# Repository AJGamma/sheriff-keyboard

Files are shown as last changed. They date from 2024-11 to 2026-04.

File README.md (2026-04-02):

# :gun:Sheriff: A :fire:BLAZINGLY FAST:fire:, Feature-rich Ergonomic Split Keyboard with Thumb Scroll Wheels

- Double rotary encoder on the thumb cluster mapped to arrow keys by default, :fire:BLAZINGLY FAST:fire: for text editing
- Higher keys on the num row, easier to reach
- Similar layout to the more traditional keyboard on notebooks, less mental overload for switching between devices
- Reversible PCB
- Fully generated, including the case, allowing easy modifications
- Configurable case generation
- Both wired and wireless support
- Generated with [Ergogen](https://github.com/ergogen/ergogen)

## :art: Gallery

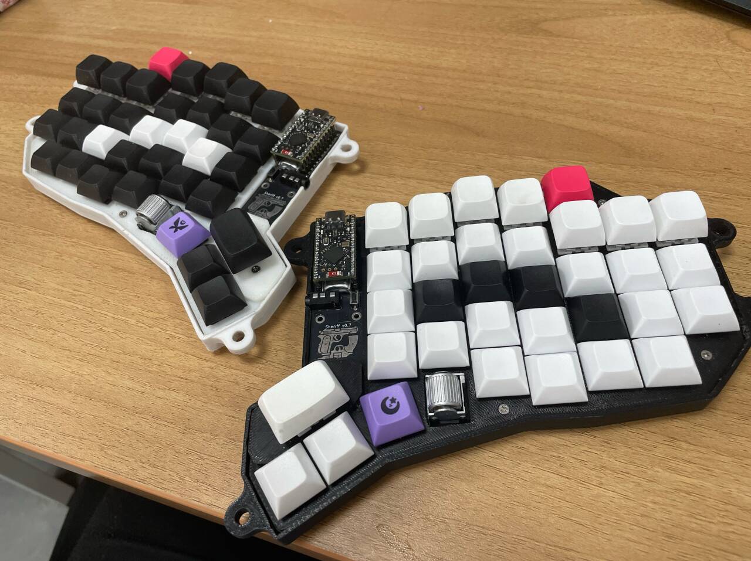
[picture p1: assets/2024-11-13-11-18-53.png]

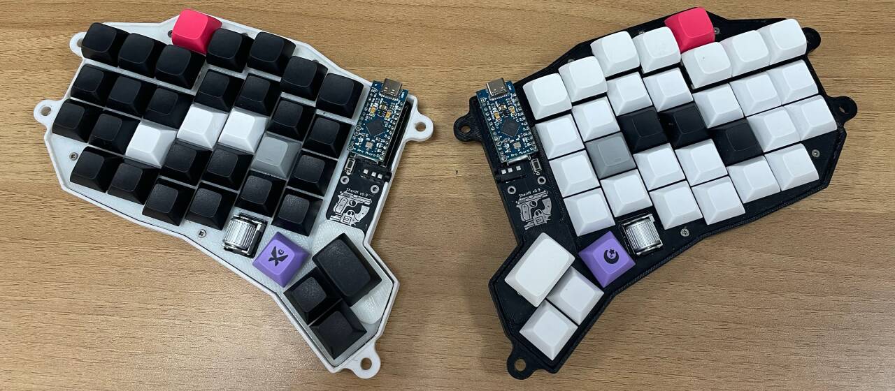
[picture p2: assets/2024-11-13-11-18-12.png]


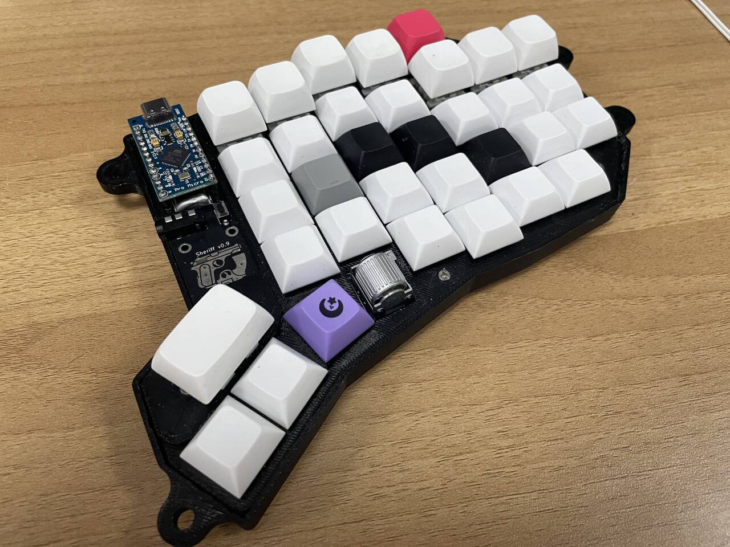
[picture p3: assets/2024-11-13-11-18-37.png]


## :sparkles: Features

### Rotary Encoders
https://github.com/user-attachments/assets/6208423b-0291-43b4-bef7-f6bb31aa5ce3

The core feature of the Sheriff is the easily accessible rotary encoders positioned on the thumb clusters.

#### Encoder behaviors

##### QMK version (`custom_scroll_layers` version)

| Behavior | Key Held  | Left Counter-clockwise | Left Clockwise | Right Counter-clockwise | Right Clockwise |
|---|---|---|---|---|---|
| Arrow key | None | Left | Right | Down | Up |
| Deletion | Backspace | Backspace | Delete | Backspace | Delete |
| Mouse wheel | Esc | Volume-down | Volume-up | Mouse wheel down | Mouse wheel up |
| Repeating | Space | Left | Right | Repeat last key | Repeat last key's alternative |
| Mouse emulation | V | Mouse left | Mouse right | Mouse down | Mouse up |
| Vim motion | W | b | w | } | { |
| Vim motion | E | ge | e | Down | Up |
| Vim undo/redo | U | u | C-r | C-r | u |
| Undo/redo | Y | C-z | C-y | C-y | C-z |
| Undo/redo | Z | C-z | S-C-z | S-C-z | C-z |
| Speed up | 8 | Next activated behavior 8 times | Next activated behavior 8 times | Next activated behavior 8 times | Next activated behavior 8 times |

##### ZMK version

| Behavior | Key Held  | Left Counter-clockwise | Left Clockwise | Right Counter-clockwise | Right Clockwise | Description |
|---|---|---|---|---|---|---|
| Arrow key | None | Left | Right | Down | Up | |
| Deletion | Backspace | Backspace | Delete | Backspace | Delete | |
| Mouse wheel | Esc | Volume-down | Volume-up | Mouse wheel down | Mouse wheel up | Sym layer |
| Repeating | Space | Left | Right | Repeat last key | Repeat last key's alternative | Nav layer |
| Mouse emulation | V | Mouse left | Mouse right | Mouse down | Mouse up | Mouse layer |
| Vim motion | W | b | w | } | { | |
| Vim motion | E | ge | e | Down | Up | |
| Speed up | 8 | Left * 8 | Right * 8 | Down * 8 | Up * 8 | |

### Configurable case generation
The case is generated with [ergogen](https://github.com/ergogen/ergogen), and the config file was written with configurability in mind. There are multiple versions of the case, including `flat`, `tented`, `sinfle-sided tented` and `lifted tented`. The parameters are highly adjustable, and customization can easily be done. See the [doc](/docs/case_customization.md) for more information.

### Easier transitions

One of the motivations for this keyboard is to make the transition from a traditional keyboard to an ergonomic one easier. That's why the default layout is mostly the same as a traditional keyboard, with the only difference being the extra keys in thumb clusters. This way, when you switch back to a traditional keyboard and you reach for the thumb cluster mods, they are simply not there, eliminating any chance of pressing the wrong key.

### Higher up num row

The key caps on the num row are higher up, making them easier to reach.

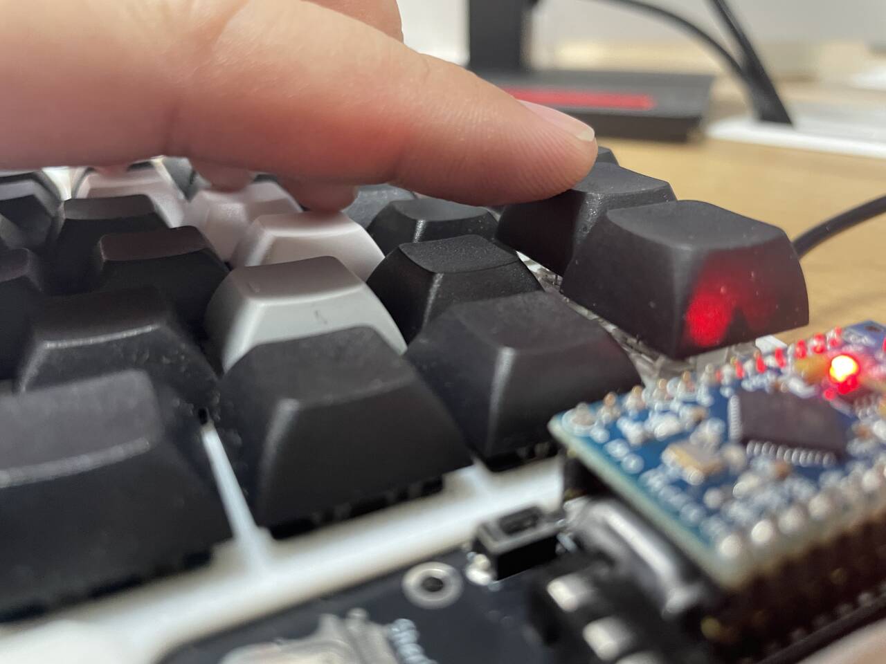
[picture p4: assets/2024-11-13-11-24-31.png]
num_row


### Both wired and wireless support
The PCB has both trrs jacks and battery pins, allowing for both wired and wireless connections.

Both ZMK(wireless) and QMK(wired) firmware are implemented; however, I've encountered several issues with the ZMK firmware, including:
- Two halves unable to pair(swapping boards did not help, neither did flashing reset firmware, and I'm 90% sure nothing's wrong with the firmware)
- Rotary encoder motions sometimes skipped

It's worth noting that I'm not using the official nice!nano boards, but rather the Pro Micro NRF52840 nice!nano v2 compatible boards, which might be the cause of the issues.

## Firmware
Supports wired usage with [QMK](https://qmk.fm/) firmware. Repository [here](https://github.com/AJGamma/sheriff-qmk-config)

Wireless usage is supported with [ZMK](https://zmk.dev/). Repository [here](https://github.com/AJGamma/sheriff-zmk-config). I couldn't get it to work properly though, detail [here](#both-wired-and-wireless-support).

## Layout

Default layer:

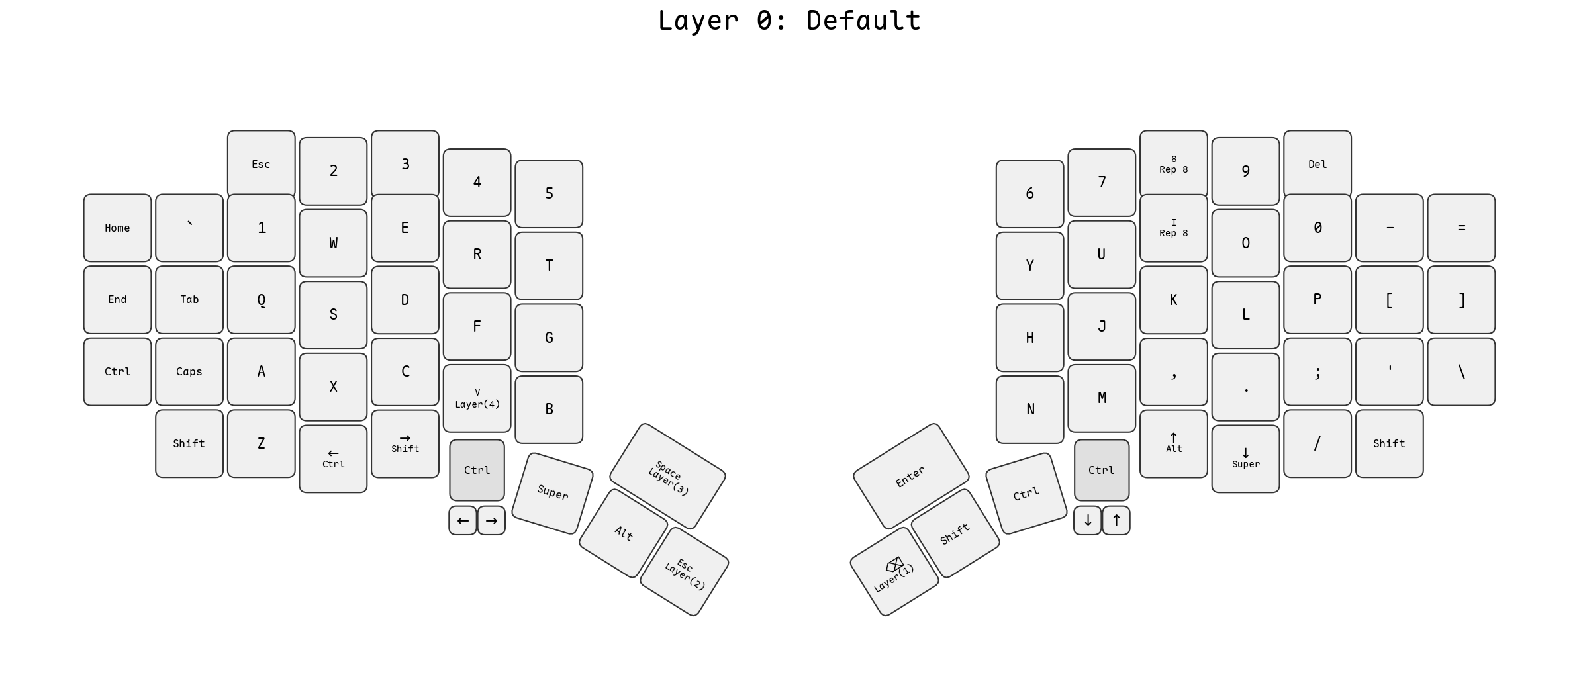
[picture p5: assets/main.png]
default layer


Layer 1:

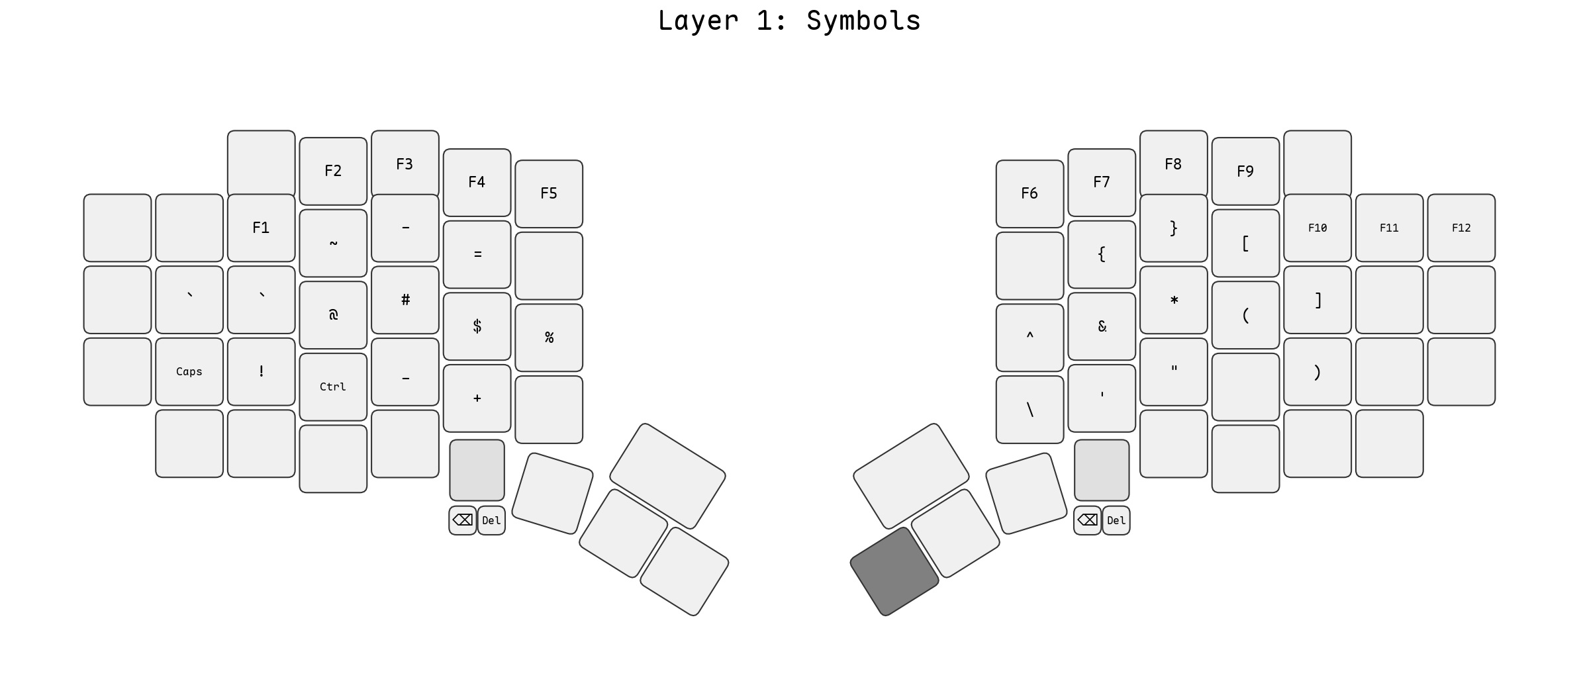
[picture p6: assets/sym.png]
Layer 1


Layer 2:

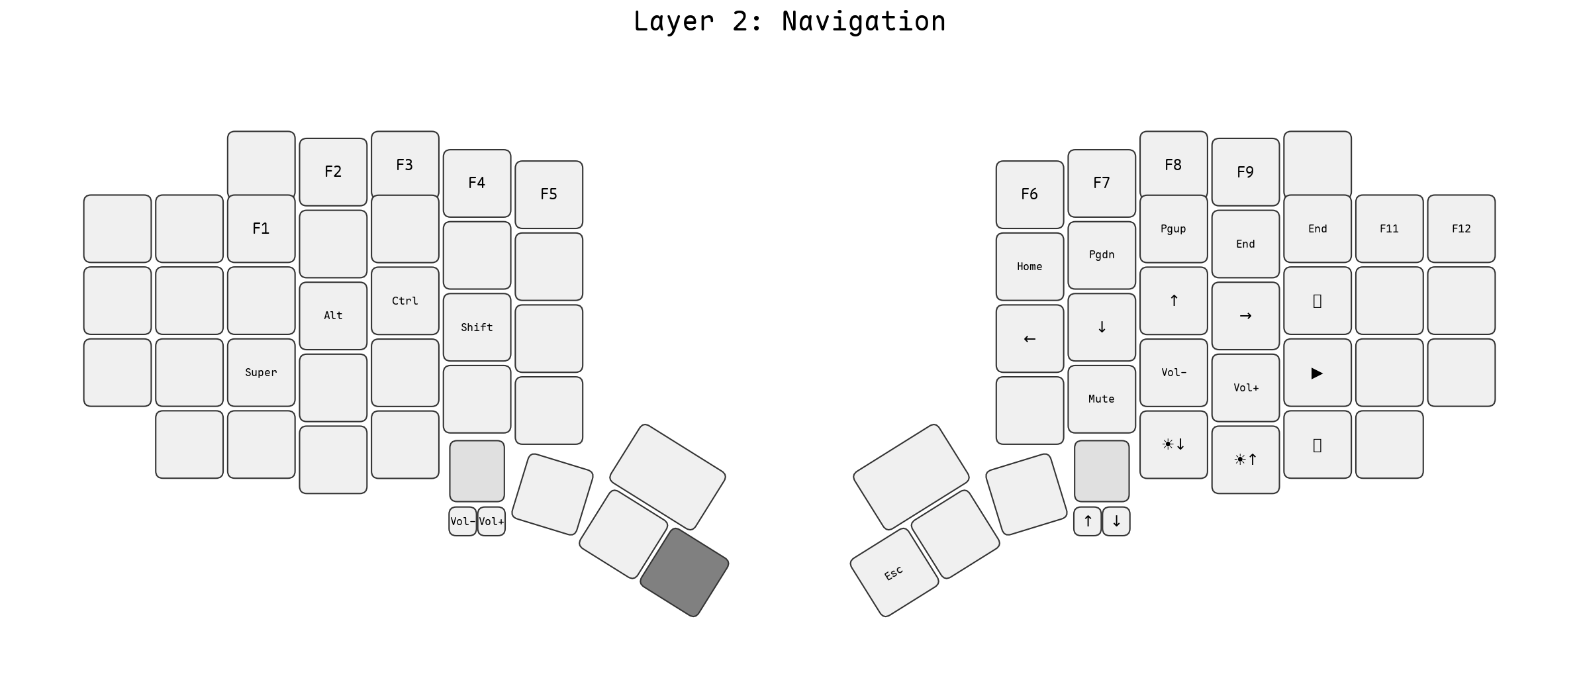
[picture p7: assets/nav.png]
Layer 2


Layer 3:

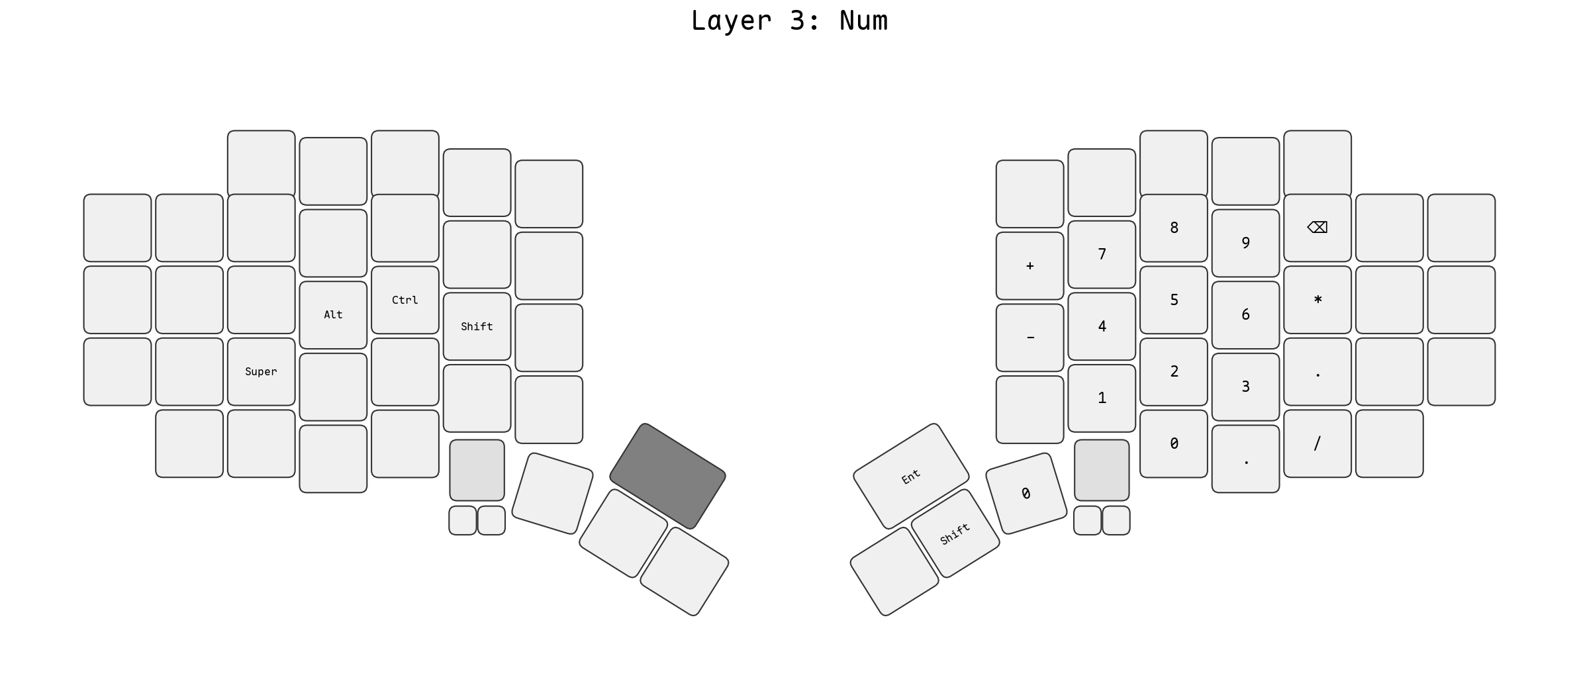
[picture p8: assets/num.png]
Layer 3


## :bulb: Inspirations

- [This amazing video by Christian Selig](https://www.youtube.com/watch?v=7UXsD7nSfDY) inspired me to build my own keyboard.
- I learned a lot from the [Corax](https://github.com/dnlbauer/corax-keyboard) keyboard, and borrowed some code as well.
- The [Arkenswoop](https://github.com/SuperFola/arkenswoop) keyboard has a similar scroll wheel feature, and I fixed my rotary encoder pin definition after checking its kicad file and the information from [this github repo](https://github.com/rroels/EVQWGD001-Pinout).

## Future work
- [ ] Build guide
- [ ] Screen
- [ ] LEDs
- [ ] More intuitive scroll wheel position and orientation
- [ ] New logo
- [ ] 3D-printed key caps
- [ ] More acquirable scroll wheel

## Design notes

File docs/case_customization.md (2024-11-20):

# Case Customization
I have written the [config](../ergogen/config.yaml) file with configurability in mind, and case customization can be easily done by following the instructions below.

## Step by Step

### 1. Modify the [config file](../ergogen/config.yaml)

Simple parameter modification can be done by changing the values in the `units` part of the config file. I have extracted most adjustable and customizable parameters to the `units` part of the config file, including wall thickness, screw diameter, tenting mount thickness, footpad diameter, etc. The variable names are pretty much self-explanatory. Modify the values to your liking.

More complex modifications can be done by modifying the `case` part of the config file. The names are pretty much self-explanatory as well.

### 2. Generate the jscad files
This can be done in two ways:

#### 2.1. Use the web-based deployments of ergogen

There are two online deployments of ergogen: the [official one](https://ergogen.xyz/) and the [unofficial one](https://ergogen.ceoloide.com/)

The online deployments of ergogen do not support uploading js footprint files, so you will receive a couple of error messages if you directly paste the config file into the input box. To avoid this, simply delete or comment out the `pcbs` part of the config file before copying. You can fold the yaml file to make it easier to read and alter.

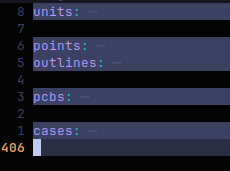
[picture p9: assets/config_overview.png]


The official one directly outputs stl files.

#### 2.2. Run ergogen locally
Install ergogen on your machine by following the instructions on the [ergogen docs](https://docs.ergogen.xyz/usage), then go to the ergogen directory and run the `ergogen` command:
```bash
git clone https://github.com/AJGamma/sheriff-keyboard
cd sheriff-keyboard/ergogen
ergogen .
```
The jscad files should be generated in the `ergogen/output/cases` directory.
<br>
<br>

You should get multiple files, among which you need two: the case file and switchplate file. There are multiple versions of the case, choose one that fits your needs.
### 3. Generate stl files
Use the [OpenJSCAD site](https://neorama.de/) to generate STL files.

### 4. Mirror the models
The generation only take care of the left side, and the right side is just a plain mirror of the left side. Nowadays most 3D-printer slicer software can easily mirror the models, so using a 3D modeling software to mirror the models isn't quite necessary. If you do need to do this, use blender, rhino or whatever. Some online tools may also work.

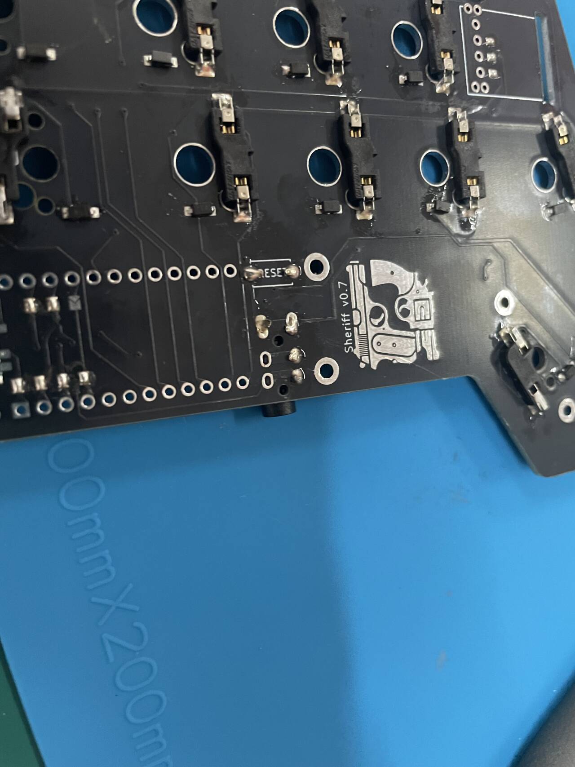
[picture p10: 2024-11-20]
assets/hot_swap.png

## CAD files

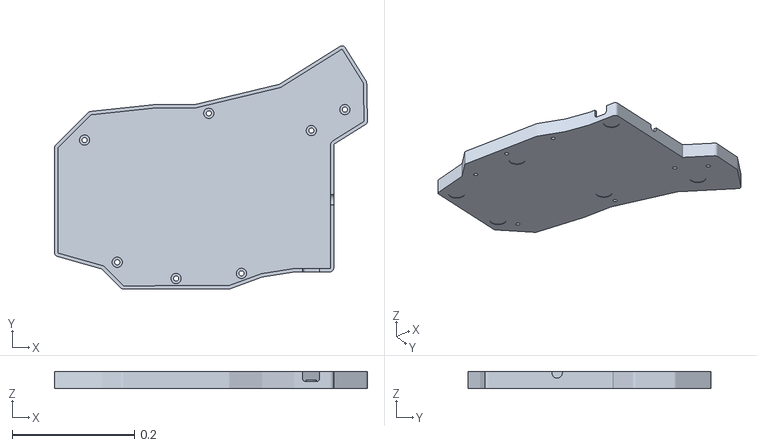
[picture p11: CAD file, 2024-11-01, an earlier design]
v1/3D_prints/cases/flat_case/right.stl
0.512 x 0.398 x 0.0281

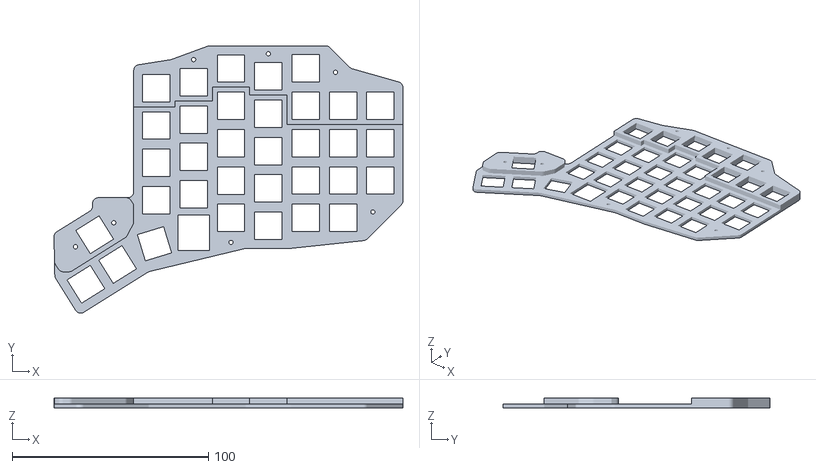
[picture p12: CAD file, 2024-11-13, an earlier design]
v1/3D_prints/cases/switchplates/right.stl
178.0 x 136.4 x 5.00

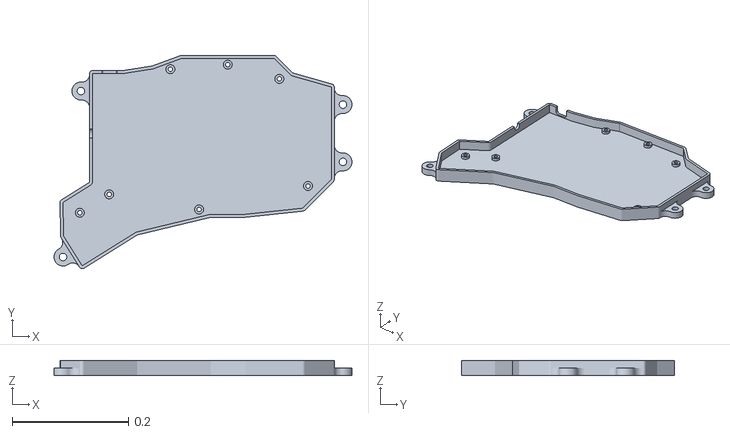
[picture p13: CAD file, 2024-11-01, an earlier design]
v1/3D_prints/cases/tented_case/right.stl
0.512 x 0.367 x 0.0258

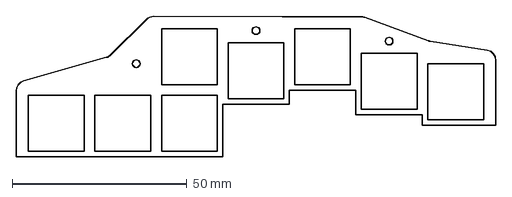
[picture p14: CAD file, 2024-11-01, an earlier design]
v1/cuts/MX_extra_switchplate_matrix_1mm_base.dxf
137.3 x 40.1 mm

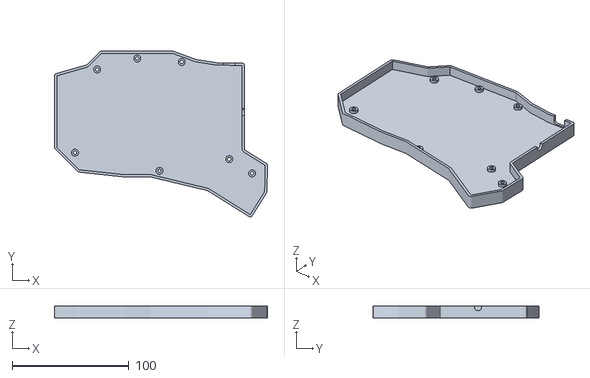
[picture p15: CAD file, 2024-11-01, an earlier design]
v1/3D_prints/cases/flat_case/left.stl
182.4 x 141.9 x 10.0

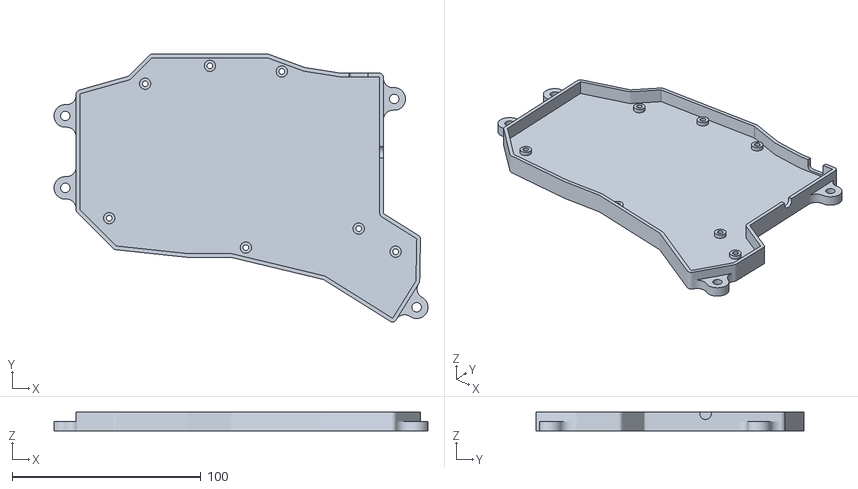
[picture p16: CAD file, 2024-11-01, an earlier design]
v1/3D_prints/cases/tented_case/left.stl
198.1 x 141.9 x 10.0

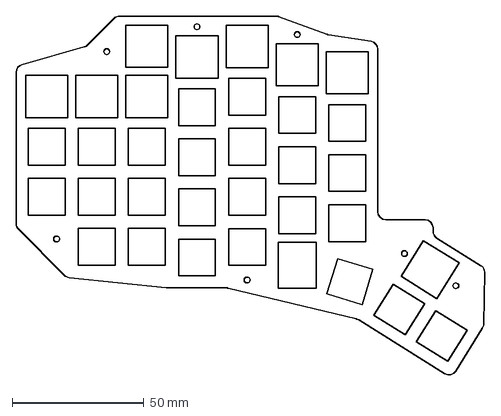
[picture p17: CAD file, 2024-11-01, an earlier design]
v1/cuts/switchplate.dxf
178.0 x 136.8 mm

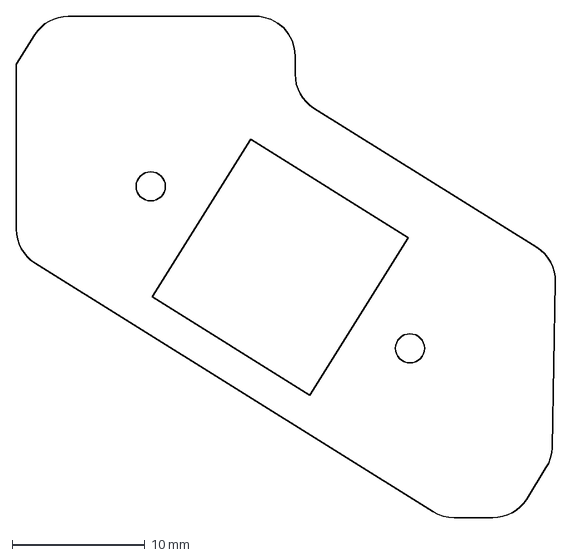
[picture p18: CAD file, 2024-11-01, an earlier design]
v1/cuts/MX_extra_switchplate_thumb.dxf
40.7 x 37.8 mm

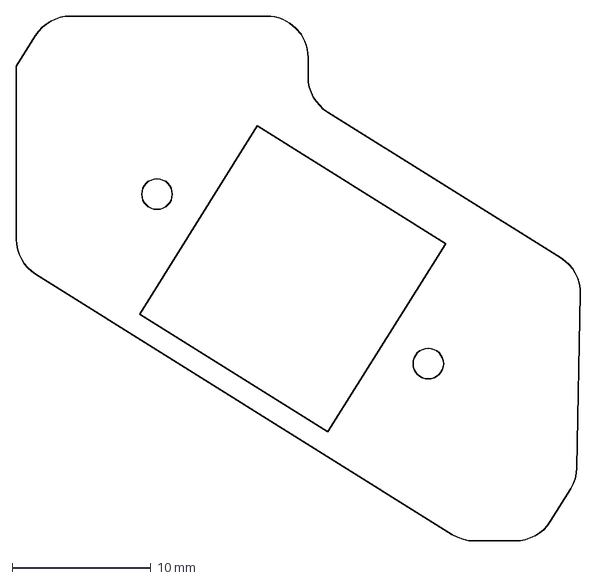
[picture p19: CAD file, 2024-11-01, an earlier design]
v1/cuts/MX_extra_switchplate_thumb_1mm_base.dxf
40.7 x 37.8 mm

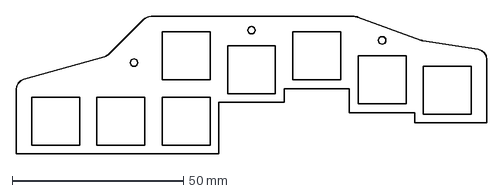
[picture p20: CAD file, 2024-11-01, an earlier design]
v1/cuts/MX_extra_switchplate_matrix.dxf
137.3 x 40.1 mm

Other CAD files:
v1/3D_prints/cases/tented_case_with_footpads/right.stl
v1/3D_prints/cases/switchplates/left.stl
v1/3D_prints/cases/tented_case_with_footpads/left.stl

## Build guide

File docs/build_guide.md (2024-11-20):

# Build guide

## TL;DR
- Make sure to connect the jumpers on the back side of each PCB (same side as where you solder the diodes and hot swap sockets)
- Case is mounted with M2*3.2 threaded screw inserts and M2 screws.
- This keyboard uses 18 MX switches and 50 Gateron ks-27 switches, and the diode directions are opposite for the two types of switches.
- See [this build guide of the Corax Keyboard for scroll wheel installation and modificaton](https://github.com/dnlbauer/corax-keyboard/blob/main/docs/BuildGuide.md) 
- My soldering order: jumpers → diodes → hot swap sockets → slider switch → reset button → TRRS jack → MCU pins → battery → encoder → MCU

## Parts list

Buying spare parts is recommended. Default values for `Wired` and `Wireless` are `Required`

| Name | Quantity  | Wired | Wireless | Notes |
|---|---|---|---|---|
| PCB | 2 | | | Download the berber files from the release page; PCB thickness 1.6 |
| Cases | 1 of each | | | Download STL files from the release page; customization is possible, see [case customization](/docs/case_customization.md) |
| MX switches and hotswap sockets | 18 | | | |
| Gateron ks-27 switches and hotswap sockets | 50 | | | |
| EVQWGD001 encoders | 2 | | | |
| SOD-123 diodes | 70 | | | I use the `1N4148W` diodes |
| 1u key caps | 66 | | | I use DSA caps for ks-27 switches and XDA caps for MX switches, to create a larger height difference |
| 1.5u key caps | 2 | | | I use XDA caps |
| M2*3*3.2 threaded screw inserts | 14 | | | you could use ones with different height |
| M2*8 screws | 4 | | | |
| M2*10 screws | 10 | | | |
| Nice!nano v2 boards | 2 | Not needed | Required | I don't think you can use them for wired version, since QMK doesn't support its MCU |
| Pro Micro boards | 2 | Required |Not needed| |
| Reset Buttons |  2 | | |  I can't find the exact part number, the distance between pins is 6mm  |
| TRRS jacks | 2 | Required | Optional | Used for power transmission for wireless version |
| 3.5mm wires | 1 | Required | Optional | Make sure to buy the ones with 4 rings! the ones with 3 won't work and may ruin your boards! |
| 3.7V lithium batteries | 2 | Not needed | Required | I use 6*12*30mm ones |
| Slider switches | 2 | Not needed | Required | K3-1296S-E1 and MK-12C02-G015 both work |
| 12-pin 2.54mm pins and sockets | 4 |  |  | Sockets are highly recommended especially if you use Pro Micro ATMEGA32U4 boards |
| 11mm silicone footpads |  |  |  | Used for flat cases |
| M5 screws | 8 |  |  | Used for tented cases, determine lengths yourself |
| M5 nuts | 16 |  |  | For tented cases |
| 7.7mm silicone rubber round caps |  |  |  | For tented cases |

## Step By Step

### 1. Connect jumpers on the back side of the PCBs

There are 9 jumpers on each side. Connect the ones on the **back** side of the PCBs, that is, on the same side as the diodes and hot swap sockets. They are positioned near the MCU and the scroll wheel.

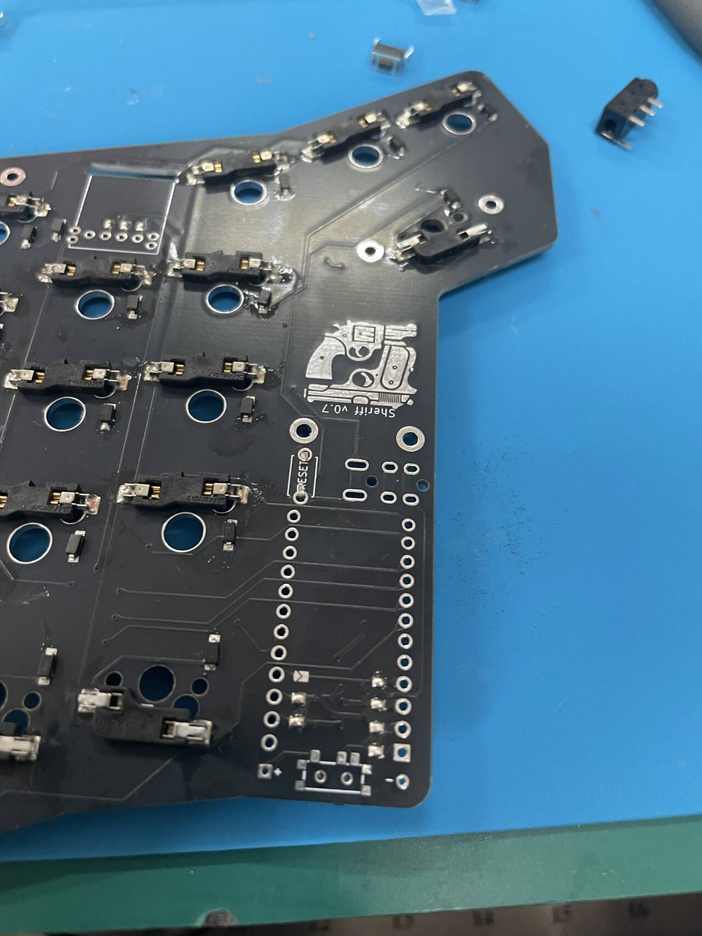
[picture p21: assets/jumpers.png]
jumpers


(The image shows 10 jumpers, that is because this is the 0.7 version and one of the jumpers were wrongly placed. The release version does not have such issue.)

### 2. Solder diodes
Make sure you solder them in the right directions. The little line on the diode should be on the same side as the line on the silk:
```raw
   ┌───────┬──┐                                               
   ┤Diode  │  ├                                               
   └───────┴──┘                                               
     │╲  │                                                    
    ─┤ 〉├─ Silk                                              
     │╱  │                                                   
```

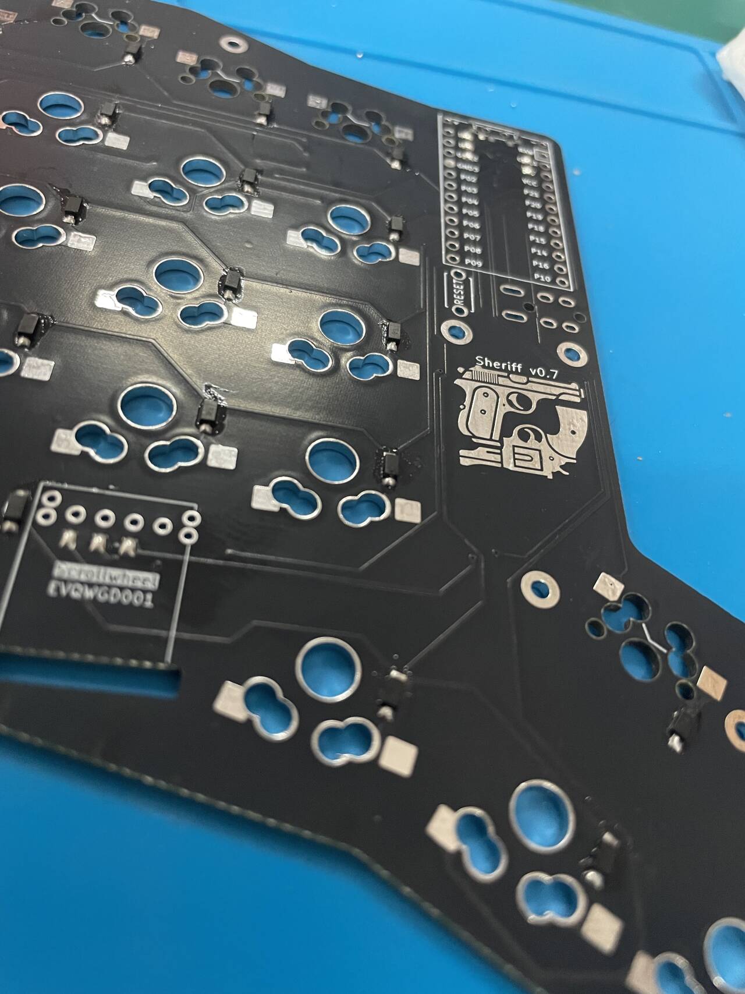
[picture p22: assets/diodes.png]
diodes


### 3. Solder hot swap sockets

### 4. Solder slider switch, reset button and trrs jack

The switch should be on the **front** side of the PCB. This is the only part which you do need to solder on the front side. The reset button and trrs jack are placed on the front side but soldered on the back side.

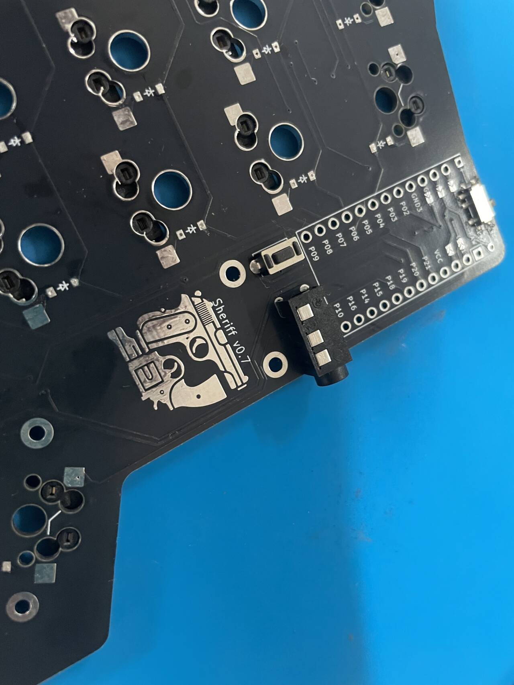
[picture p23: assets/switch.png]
switch


### 5. Solder MCU pins

Place the MCU pins on the front side, use tape or an actual MCU(no need to be soldered) to hold them in place, then solder the pins on the back side.

### 6. Solder battery
Place the battery on the front side of the PCB, then solder the wires on the back.

Eventually your MCU, slider and battery should look like this:

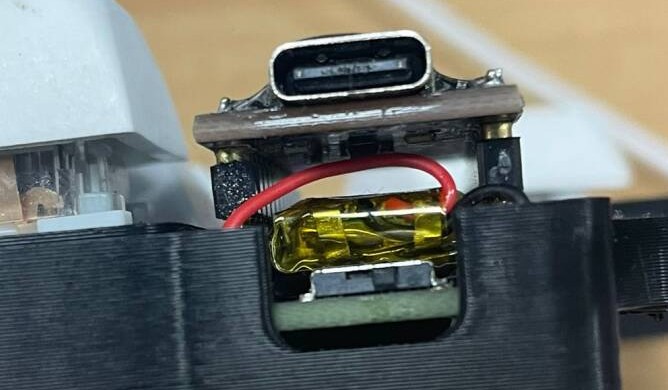
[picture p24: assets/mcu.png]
mcu


### 7. Solder encoders
Remove the little column near the pins (required) and crop the extrusion on the other end (optional but recommended). Install and solder.

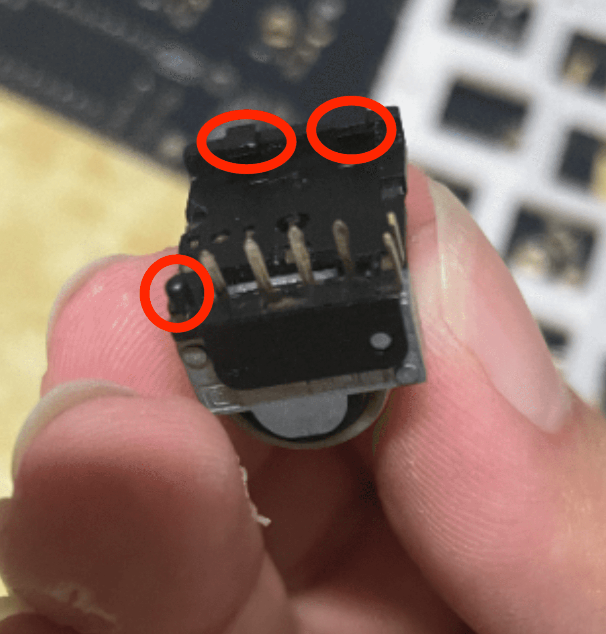
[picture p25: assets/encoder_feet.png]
encoder_feet


### 8. Install threaded screw inserts

Simply put, this is done by heating the inserts with a soldering iron and pushing them into the holes on the case. However, if your 3D printer is not well-calibrated, there may be a size error and you holes won't perfectly align with the ones on the PCB. To address this problem, you can insert longer screws first through the holes, screw the inserts onto the screws, and then heat them & push/pull.

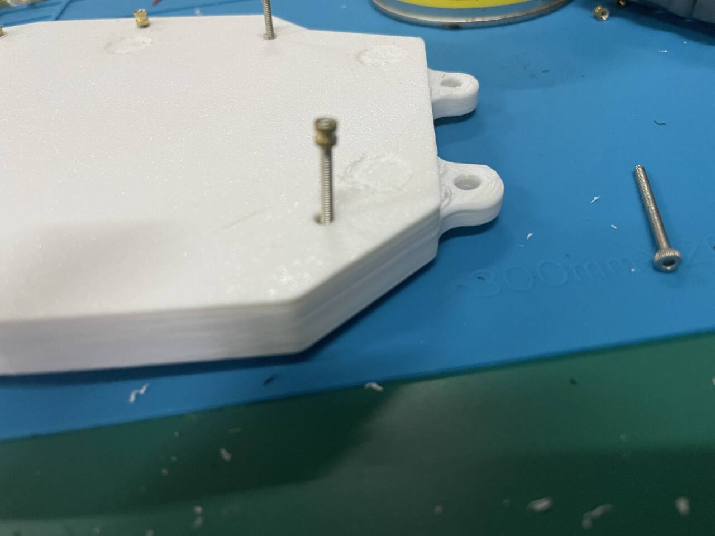
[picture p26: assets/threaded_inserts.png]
threaded_inserts

<br>
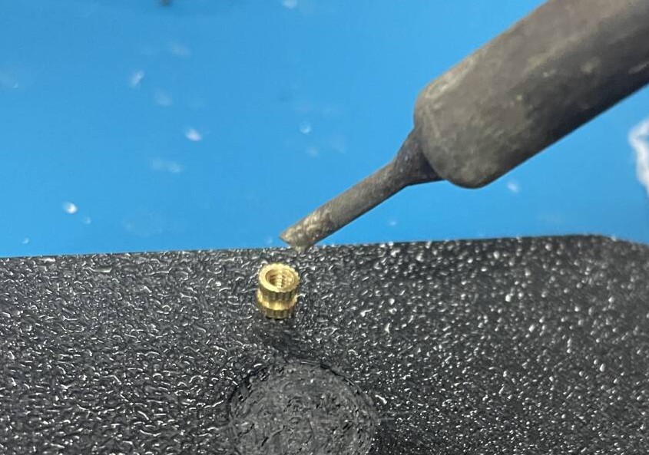
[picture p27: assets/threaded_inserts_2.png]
threaded_inserts_3


### 9. Assemble the case, install the switches and key caps
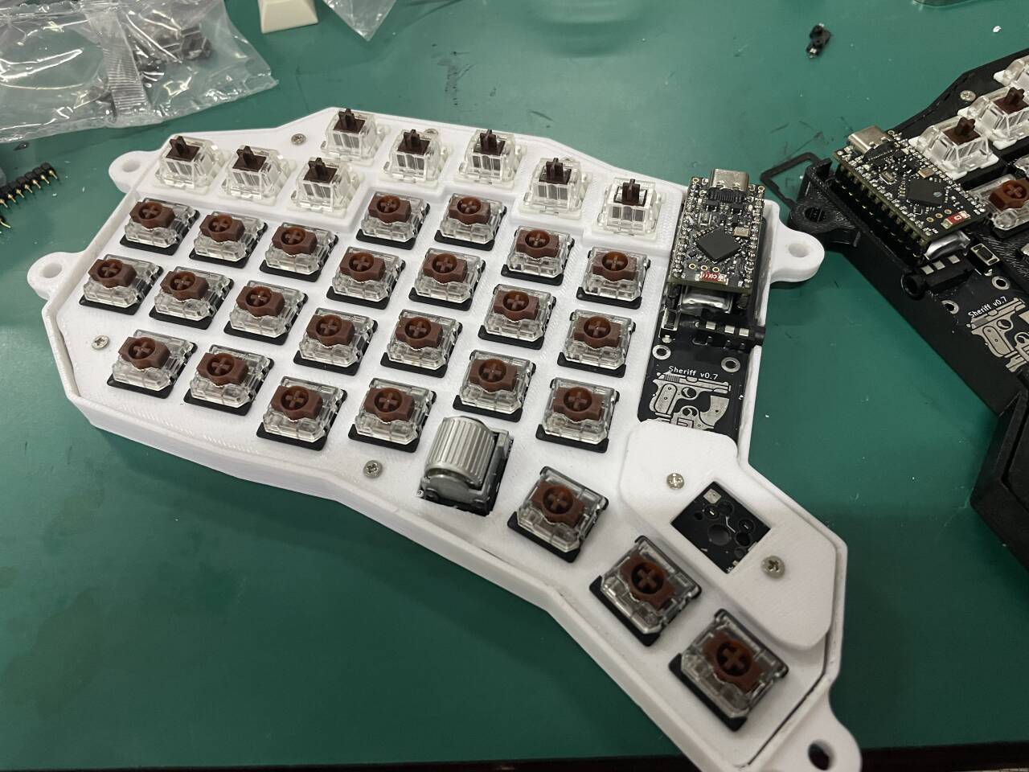
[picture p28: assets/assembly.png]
assembly


### 10. Install footpads/tenting screws

#### 10.1 Footpads
Because the footpad slots need supports, you may not get a very even surface for the footpads, and the double-sided tapes that come with the footpads may not work well. Remove the tapes and use glue instead.

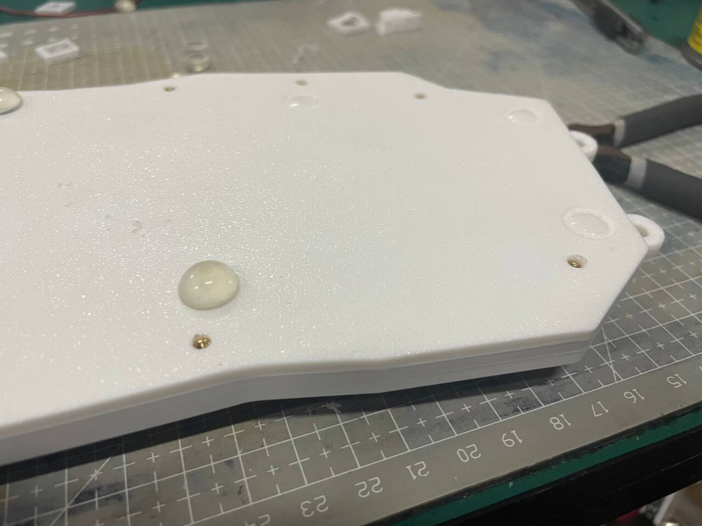
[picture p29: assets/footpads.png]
footpads


#### 10.2 Tenting screws
Use M5 bolts and nuts to tent the case, and use silicone rubber caps for better grip.
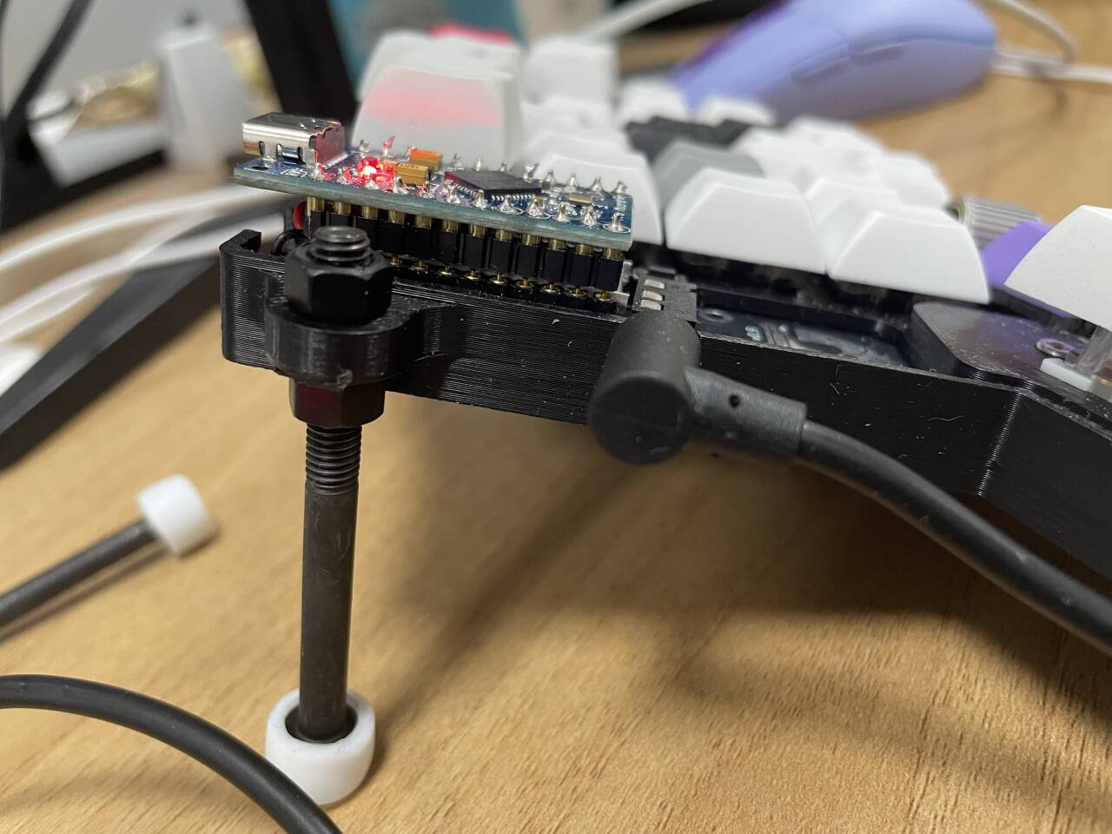
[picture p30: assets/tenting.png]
tenting


### 11. Flash the firmware
See firmware repos.

### 12. Connect to your device
If you're using wired build, connect the two halves with a TRRS cable **with 4 rings**. Connect the left half to your device.

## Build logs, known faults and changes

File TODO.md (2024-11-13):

### TODO
- Hardware
    - [X] Jumper sides
        - [X] Config file
        - [X] PCB
    - [X] Thumb cluster inner key cap
    - [X] Scroll wheel case cutout
    - [X] Scroll wheel pin testing
    - [ ] Better wall height
- Firmware
    - ZMK
        - [ ]Mouse emulation
        - [ ]Single-handed layer
    - QMK
        - [X] Basic config

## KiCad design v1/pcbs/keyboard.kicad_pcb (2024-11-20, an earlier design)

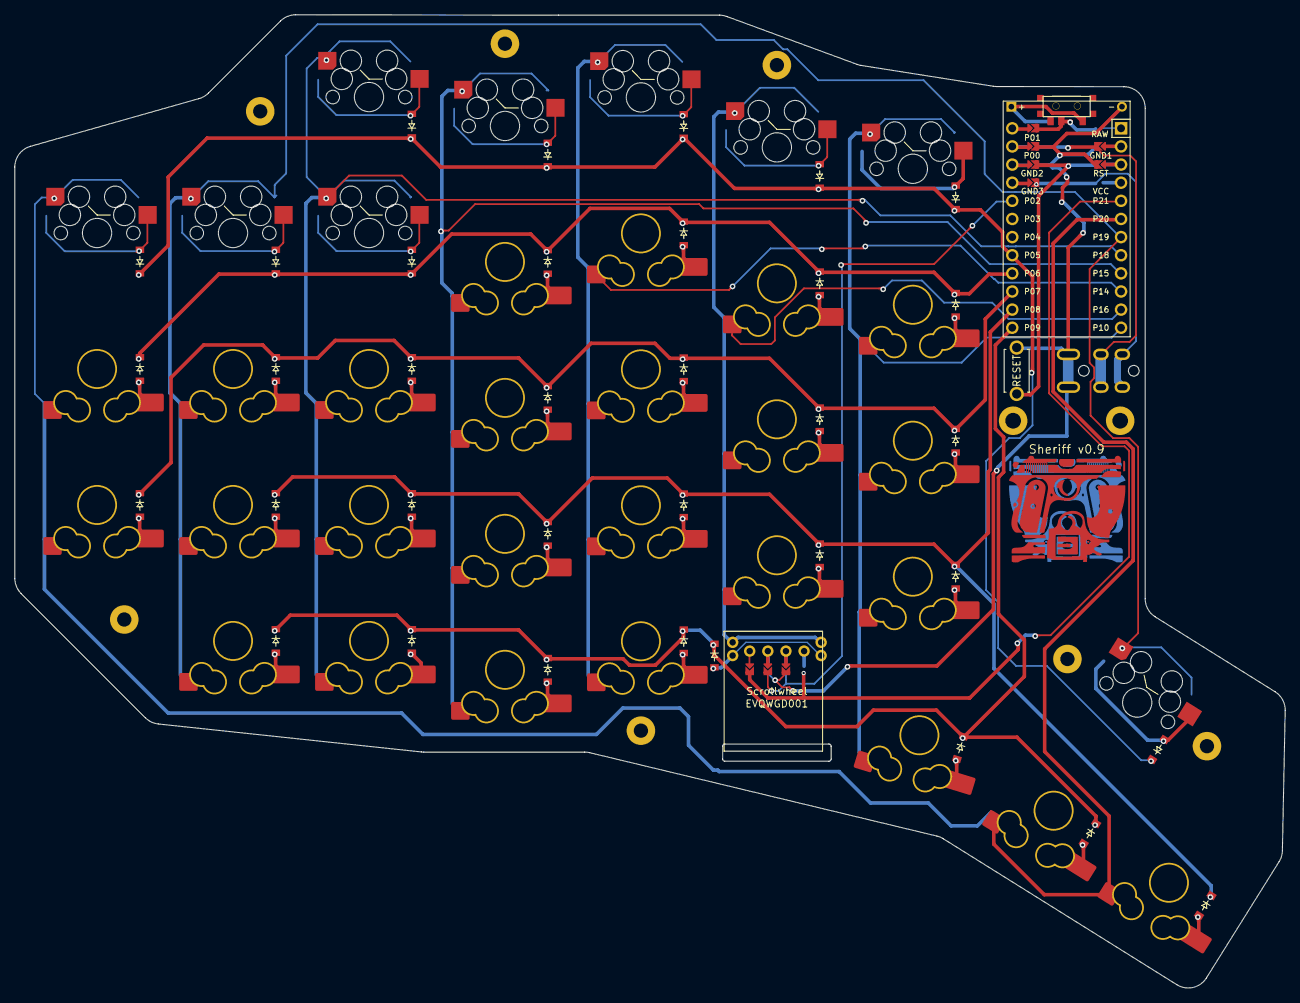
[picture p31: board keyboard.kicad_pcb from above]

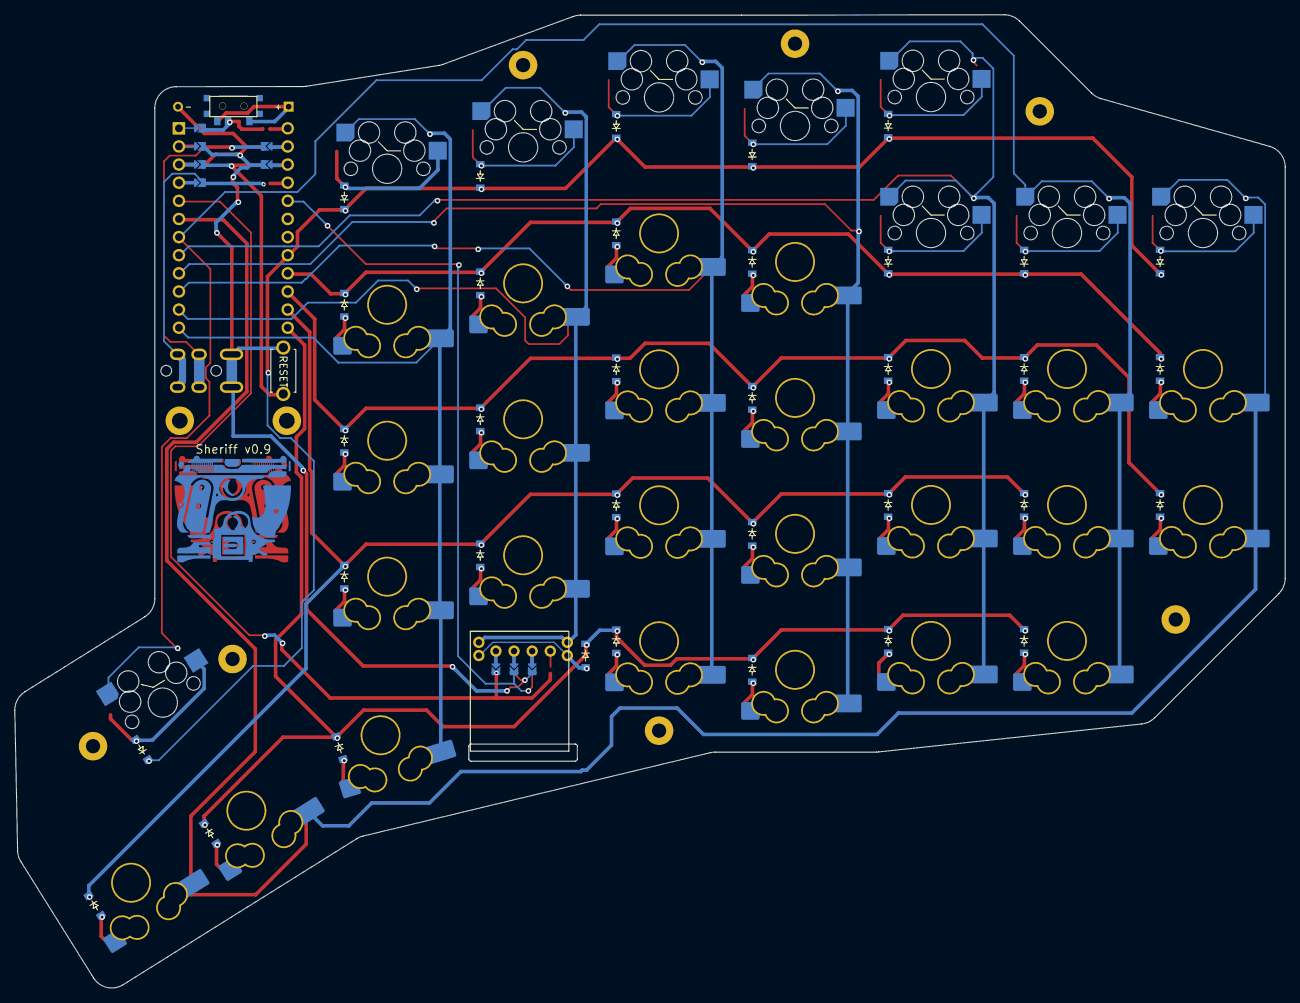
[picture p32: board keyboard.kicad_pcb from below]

Board: 2 copper layers, 178.0 x 136.4 mm, 100 parts (68 on the bottom side), 63 nets.

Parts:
D1, D2, D3, D4, D5, D6, D7, D8, D9, D10, D11, D12, D13, D14, D15, D16, D17, D18, D19, D20, D21, D22, D23, D24, D25, D26, D27, D28, D29, D30, D31, D32, D33, D34: diode_tht_sod123
D35: ComboDiode
J1, J2, J3, J4, J5, J6, J7, J8, J9, J10, J11, J12, J13, J14, J15, J16, J17, J18: Jumper
MCU1: ProMicro
S1, S2, S3, S4, S5, S6, S7, S8, S9, S10, S11, S12, S13, S14, S15, S16, S17, S18, S19, S20, S21, S22, S23, S24, S25: switch_gateron_ks27_ks33
S26, S27, S28, S29, S30, S31, S32, S33, S34: switch_mx
T1: SPDT_C128955
TRRS1: trrs_pj320a (reversible, symmetric)
_1: ResetSW
_2, _3, _4, _5, _6, _7, _8, _9, _10: Hole

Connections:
ENCA: J1.2, J4.2, MCU1.5
ENCB: J2.2, J5.2, MCU1.17
ENCB_GND: J2.1, J6.1
GND: J3.2, J6.2, J7.2, J10.2, J14.2, J18.2, TRRS1.4, _1.2
GND_ENCB: J3.1, J5.1
GND_RST: J10.1, J17.1, MCU1.15
GND_VCC: J13.1, MCU1.16
GND_serial: J7.1, J15.1, MCU1.2
P1_RAW: J16.1, MCU1.13
RAW: J9.2, J16.2, T1.2
RAW_P1: J9.1, MCU1.1
RST: J11.2, J17.2, _1.1
RST_GND: J11.1, J18.1, MCU1.3
VCC: J12.2, J13.2, TRRS1.2
VCC_GND: J12.1, MCU1.4
col0: MCU1.6, S1.1, S2.1, S24.1, S25.1, S26.2
col1: MCU1.7, S3.1, S4.1, S5.1, S27.2, S34.2
col2: MCU1.8, S6.1, S7.1, S8.1, S28.2, S29.2
col3: MCU1.9, S9.1, S10.1, S11.1, S12.1, S30.2
col4: MCU1.10, S13.1, S14.1, S15.1, S16.1, S31.2
col5: MCU1.11, S17.1, S18.1, S19.1, S32.2
col6: MCU1.12, S20.1, S21.1, S22.1, S23.1, S33.2
home_high: D34.2, S34.1
home_low: D24.2, S24.2
index_bottom: D17.2, S17.2
index_home: D18.2, S18.2
index_num: D32.2, S32.1
index_top: D19.2, S19.2
inner_bottom: D20.2, S20.2
inner_home: D21.2, S21.2
inner_low: D23.2, S23.2
inner_num: D33.2, S33.1
inner_top: D22.2, S22.2
middle_bottom: D14.2, S14.2
middle_home: D15.2, S15.2
middle_mod: D13.2, S13.2
middle_num: D31.2, S31.1
middle_top: D16.2, S16.2
outer1_bottom: D4.2, S4.2
outer1_home: D5.2, S5.2
outer1_mod: D3.2, S3.2
outer1_top: D27.2, S27.1
outer2_bottom: D1.2, S1.2
outer2_home: D2.2, S2.2
outer2_top: D26.2, S26.1
outer_low: D25.2, S25.2
pinky_bottom: D7.2, S7.2
pinky_home: D8.2, S8.2
pinky_mod: D6.2, S6.2
pinky_num: D29.2, S29.1
pinky_top: D28.2, S28.1
ring_bottom: D10.2, S10.2
ring_home: D11.2, S11.2
ring_mod: D9.2, S9.2
ring_num: D30.2, S30.1
ring_top: D12.2, S12.2
row0: D26.1, D29.1, D30.1, D31.1, D32.1, D33.1, D34.1, MCU1.20
row1: D2.1, D12.1, D16.1, D19.1, D22.1, D27.1, D28.1, MCU1.21
row2: D1.1, D5.1, D8.1, D11.1, D15.1, D18.1, D21.1, MCU1.22
row3: D4.1, D7.1, D10.1, D14.1, D17.1, D20.1, D25.1, MCU1.23
row4: D3.1, D6.1, D9.1, D13.1, D23.1, D24.1, D35.1, MCU1.24
serial: J8.2, J15.2, TRRS1.3
serial_GND: J8.1, J14.1, MCU1.14

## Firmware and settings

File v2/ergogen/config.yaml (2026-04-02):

units:
  kx: U
  ky: U
  padding: 4
  px: kx+padding
  py: ky+padding
  sx: 0.5px
  sy: 0.5py
  mcu_height: 34
  mcu_width: 18
  # distance keys to mcu
  mcu_padding: 1.5
  scrollwheel_width: 18
  scrollwheel_height: 16
  screw_diameter: 4
  screw_hole: 2
  switchplate_switch_cutout: 14
  switchplate_switch_base_cutout: 16
  switchplate_scrollwheel_cutout_x: 18
  switchplate_scrollwheel_cutout_y: 16
  switchplate_screw_diameter: 3.3
  switchplate_screw_hole: 2.2
  screen_screw_diameter: 4
  screen_screw_hole: 2.2

  usb_width: 10
  usb_height: 20
  usb_fillet: 2

  trrs_width: 6
  trrs_height: 20
  trrs_radius: 2.5

  thumb_radius: 60
  thumb_cluster_angle: 26
  thumb_cluster_start_angle: 74
  thumb_cluster_rotation: -80

  pcb_thickness: 1.6

  # ---------------------------------------------- The parameters below can be changed. The names are pretty much self-explanatory ----------------------------------------------

  case_screw_insert_diameter: 3
  case_standoff_diameter: 6

  case_base_thickness: 3
  case_support_height: 2
  case_wall_thickness: 2
  case_wall_height: 4
  case_wall_margin: 0.5     # Margin between the wall and the board

  footpad_diameter: 11
  footpad_slot_depth: 0.4

  tenting_mount_hole_diameter: 5
  tenting_mount_perimeter_diameter: 12
  tenting_mount_thickness: 4
  tenting_mount_lift_height: 4


points:
  zones:
    #   ----------------------- Key switches -----------------------

    matrix:

      anchor.shift: [50, -150]
      key:
        tags: [switch]
        padding: 1ky
        spread: 1kx
        height: 1ky
        width: 1kx
      columns:
        outer2:
          rows:
            mod:
              skip: true
            bottom:
              row_net: row2
            home:
              row_net: row1
            top:
              row_net: row0
              tags: [switch_high]
            num:
              skip: true
          key.column_net: col0
        outer1:
          # rows.mod.skip: true
          rows.num.skip: true
          rows.top.tags: [switch_high]
          key.column_net: col1
        pinky:
          # for pinky(and the two rows above, home position is actually the bottom row, and the "num" row here is an extra row for ring finger)
          rows.top.tags: [switch_high]
          key.column_net: col2
        ring:
          key:
            stagger: 15 - ky
            column_net: col3

        middle:
          key:
            stagger: 4
            column_net: col4
          rows.mod.skip: true

        index:
          key:
            stagger: -7
            column_net: col5
        inner:
          rows.mod.skip: true
          key:
            stagger: -3
            column_net: col6
      rows:
        # Four main rows, one partial row.
        mod:
          row_net: row4
        bottom:
          row_net: row3
        home:
          row_net: row2
        top:
          row_net: row1
        num:
          row_net: row0
          tags: [switch_high]

    thumb_center:
      key.skip: true
      anchor:
        ref: matrix_index_home
        shift: [3, -95]

    thumb_cluster:
      key:
        tags: [switch]
        padding: kx
        spread: ky
        height: 1ky
        width: 1kx
        # rotate: -90
      anchor:
        ref: thumb_center
        orient: thumb_cluster_start_angle - thumb_cluster_angle
        shift: [thumb_radius - 0.5kx, ky]
        rotate: thumb_cluster_rotation
      columns:
        inner:
          rows.high.skip: true
          rows.low:
            row_net: row4
            column_net: col6
          key.rotate: 15
          key.shift: [-2.5, -1]
        home:
          rows.high:
            column_net: col1
            row_net: row0
            shift: [0.1kx, 0]
            width: 1.6kx
          rows.low:
            column_net: col0
            row_net: row4

        outer:
          rows.high.skip: true
          rows.low:
            column_net: col0
            row_net: row3
      rows:
        low:
          tags: [switch]
        high:
          tags: [thumb_switch_high]


   #   ----------------------- Thumb cluster reference points -----------------------
    thumb_outer_ref:
      anchor:
        ref: thumb_center
        orient: thumb_cluster_start_angle - 40
        shift: [thumb_radius, 0]
      columns:
        point.key:
          width: 3
          height: 3

    thumb_home_ref:
      anchor:
        ref: thumb_center
        orient: thumb_cluster_start_angle - 20
        shift: [thumb_radius, 0]
      columns:
        point.key:
          width: 3
          height: 3

    thumb_inner_ref:
      anchor:
        ref: thumb_center
        orient: thumb_cluster_start_angle
        shift: [thumb_radius, 0]
      columns:
        point.key:
          width: 3
          height: 3
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

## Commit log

2024-10-23 pcbs and cases
    [keyboard.kicad_pcb]
2024-10-26 routed pcb
    [keyboard.kicad_pcb]
2024-10-26 added teardrops
    [keyboard.kicad_pcb]
2024-10-27 first release 0.7
    [MX_extra_switchplate_matrix.dxf, MX_extra_switchplate_matrix_1mm_base.dxf, MX_extra_switchplate_thumb.dxf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]
2024-10-28 lifted tenting mounts
2024-11-02 switchplate thickness update
2024-11-04 fixed rotor pinout, updated jumper side
    [keyboard.kicad_pcb]
2024-11-13 updated readme; fixed switchplate
    [left.stl, right.stl]
2024-11-13 fixed switchplate
    [right.stl]
2024-11-14 updated switchplate model
    [left.stl, right.stl]
2024-11-17 updated build guide; updated scroll wheel behavior table
2024-11-20 completed build guide and case customization doc
2024-12-12 refactored: 2 versions
    [MX_extra_switchplate_matrix.dxf, MX_extra_switchplate_matrix_1mm_base.dxf, MX_extra_switchplate_thumb.dxf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]
2024-12-12 removed output
    [MX_extra_switchplate_matrix.dxf, MX_extra_switchplate_matrix_1mm_base.dxf, MX_extra_switchplate_thumb.dxf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]
